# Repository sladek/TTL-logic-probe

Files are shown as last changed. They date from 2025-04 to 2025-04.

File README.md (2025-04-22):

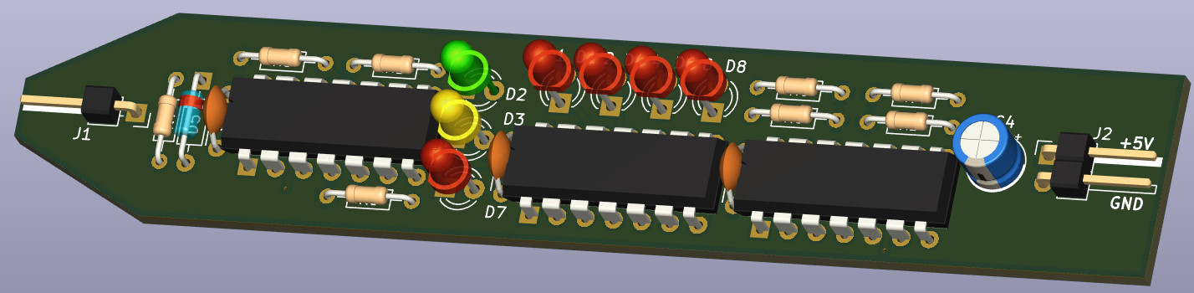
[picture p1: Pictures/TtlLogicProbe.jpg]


## TTL logic probe with counter

The probe indicates TTL levels "1", "0", "Floating" and contains also counter (74LS93) with LEDs to indicate impulses. 

[Schematics](Documents/TTL-Logic-Probe.pdf)

Interesting part is the detection of "open"/"floating" input. The crcuit is shown in the following picture:

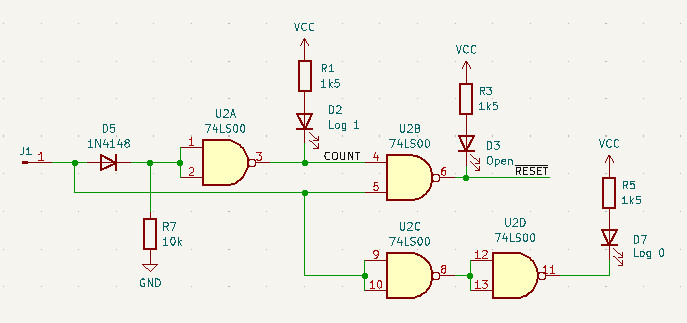
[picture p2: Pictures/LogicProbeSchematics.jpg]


The input of U2A (which forms just a simple inverter) is connected to the ground, which imposes log 0 if the input is floating. In that case there is log 1 on input 4 of U2B and also log 1 on input 5 (input 5 is floating, so it imposes log 1). In this case the output 6 is log 0, so LED D3 is on. For log 0 and log 1 on input, the circuit just follows the logic functions of 74LS00. This means that the circuit behaves predictably based on the input combinations, allowing for reliable operation of the LEDs. Consequently, users can visually monitor the status of the inputs, as the LED indicators provide immediate feedback on the circuit's logic state.

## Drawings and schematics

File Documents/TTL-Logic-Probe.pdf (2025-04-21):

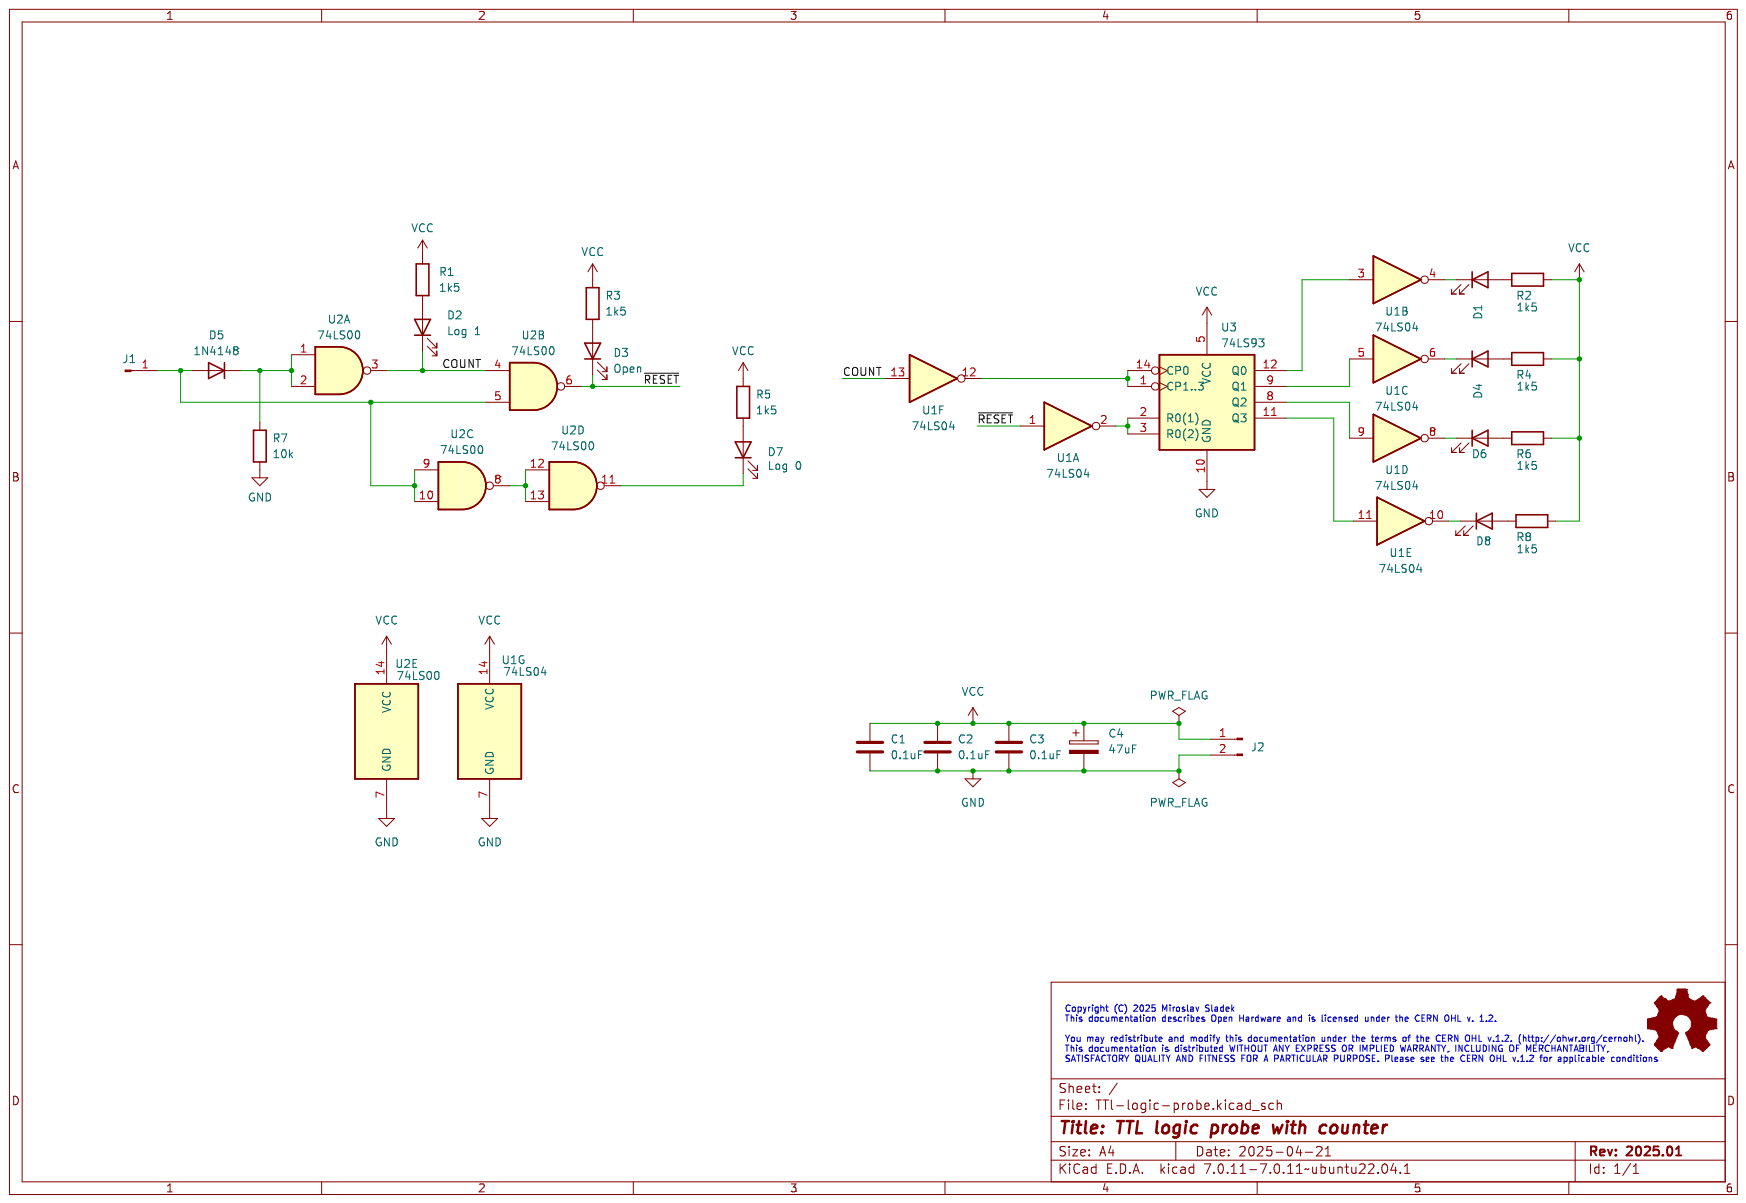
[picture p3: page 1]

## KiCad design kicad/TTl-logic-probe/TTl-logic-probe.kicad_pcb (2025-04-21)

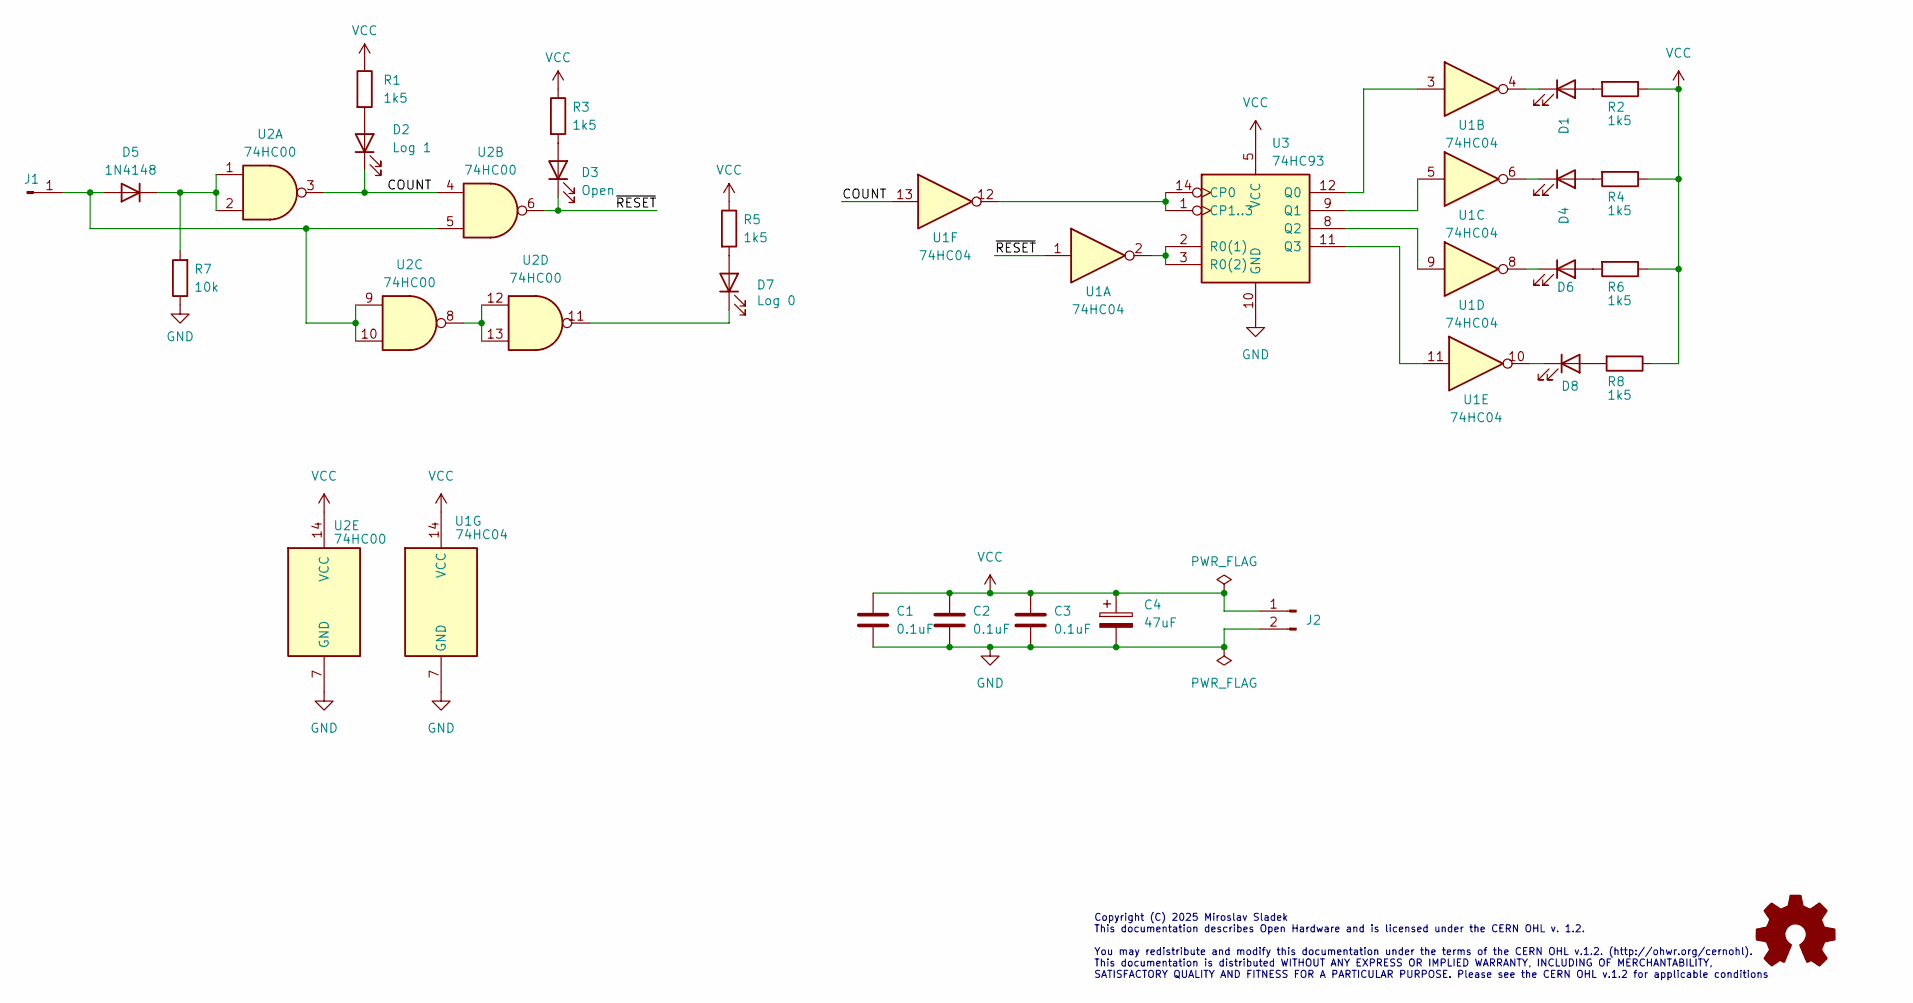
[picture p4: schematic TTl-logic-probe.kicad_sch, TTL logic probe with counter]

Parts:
C1, C2, C3: 0.1uF; C_Disc_D4.3mm_W1.9mm_P5.00mm
C4: 47uF; CP_Radial_D5.0mm_P2.00mm
D1: 1; LED_D3.0mm
D2: Log 1; LED_D3.0mm
D3: Open; LED_D3.0mm
D4: 2; LED_D3.0mm
D5: 1N4148; D_DO-35_SOD27_P7.62mm_Horizontal
D6: 4; LED_D3.0mm
D7: Log 0; LED_D3.0mm
D8: 8; LED_D3.0mm
J1: Conn_01x01_Pin; PinHeader_1x01_P2.54mm_Horizontal
J2: Conn_01x02_Pin; PinHeader_1x02_P2.54mm_Horizontal
R1, R2, R3, R4, R5, R6, R8: 1k5; R_Axial_DIN0204_L3.6mm_D1.6mm_P7.62mm_Horizontal
R7: 10k; R_Axial_DIN0204_L3.6mm_D1.6mm_P7.62mm_Horizontal
U1: 74HC04; DIP-14_W7.62mm
U2: 74HC00; DIP-14_W7.62mm
U3: 74HC93; DIP-14_W7.62mm

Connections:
/COUNT: D2.1 (K), U1.13, U2.3, U2.4
/~RESET: D3.1 (K), U1.1, U2.6
GND: C1.2, C2.2, C3.2, C4.2, J2.2, R7.1, U1.7 (GND), U2.7 (GND), U3.10 (GND)
unnamed: D1.2 (A), R2.2
unnamed: D1.1 (K), U1.4
unnamed: D2.2 (A), R1.2
unnamed: D3.2 (A), R3.2
unnamed: D4.2 (A), R4.2
unnamed: D4.1 (K), U1.6
unnamed: D5.2 (A), J1.1, U2.5, U2.9, U2.10
unnamed: D5.1 (K), R7.2, U2.1, U2.2
unnamed: D6.2 (A), R6.2
unnamed: D6.1 (K), U1.8
unnamed: D7.2 (A), R5.2
unnamed: D7.1 (K), U2.11
unnamed: D8.2 (A), R8.2
unnamed: D8.1 (K), U1.10
unnamed: U2.8, U2.12, U2.13
unnamed: U1.12, U3.1 (CP1..3), U3.14 (CP0)
unnamed: U1.3, U3.12 (Q0)
unnamed: U1.5, U3.9 (Q1)
unnamed: U1.9, U3.8 (Q2)
unnamed: U1.11, U3.11 (Q3)
unnamed: U1.2, U3.2 (R0(1)), U3.3 (R0(2))
VCC: C1.1, C2.1, C3.1, C4.1, J2.1, R1.1, R2.1, R3.1, R4.1, R5.1, R6.1, R8.1, U1.14 (VCC), U2.14 (VCC), U3.5 (VCC)

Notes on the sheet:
Copyright (C) 2025 Miroslav Sladek This documentation describes Open Hardware and is licensed under the CERN OHL v. 1.2. You may redistribute and modify this documentation under the terms of the CERN OHL v.1.2. (http://ohwr.org/cernohl). This documentation is distributed WITHOUT ANY EXPRESS OR IMPL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

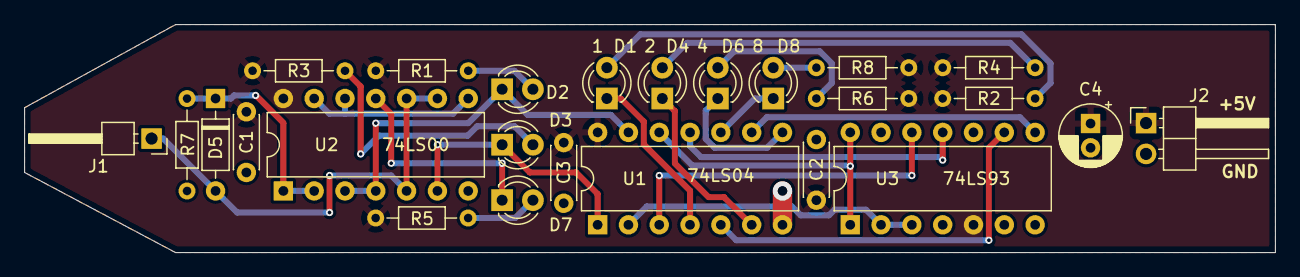
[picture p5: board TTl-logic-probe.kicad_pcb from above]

Board: 2 copper layers, 103.1 x 18.8 mm, 25 parts (0 on the bottom side), 25 nets.
